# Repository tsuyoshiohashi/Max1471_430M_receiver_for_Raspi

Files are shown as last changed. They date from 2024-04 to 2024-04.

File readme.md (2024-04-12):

# MAX1471＋AD5700 430MHz AFSK receiver for Raspi

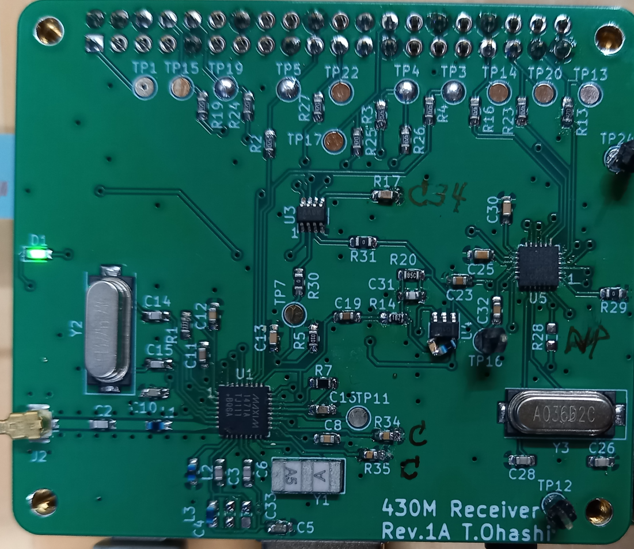
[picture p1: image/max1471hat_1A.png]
Max1471_hat max1471_hat


Receive 1200bps AFSK modulated waves in the 430Mhz band with RaspberryPi and an expansion board (MAX1471 + AD5700 430M radio hat, home made, see hat directory).
(In the photo, the LC series trap is directly attached to the U4 pin, but it has been modified in the circuit diagram.)

・The receiving frequency is fixed at the frequency determined by the XTAL frequency.

-Confirmed reception of a 1200bps AFSK signal in Asynchronous format (UART) sent by Gnuradio+Pluto. 

Please refer to the gnuradio directory for the transmitting program.

# Environment where operation has been confirmed
Raspi3B+　Raspberry Pi OS(bookworm)

You need to install pigpio.

# HAT configuration and operation
I use Analog Devices' MAX1471 for reception and AD5700 for AFSK demodulation.

MAX1471 operates in Continuous Receive Mode.

## receiving data
The received data RXD is connected to GPIO15 (pin10) of Raspi, and if the received data is in UART format, it can be treated as /dev/ttyAMA0 by setting UART on Raspi, and it can be displayed on minicom.
(Device name may vary depending on Raspino model)

`Example) $ cat /dev/ttyAMA0`

`Example) $ minicom -b 1200 -D /dev/ttyAMA0`

Since there is no squelch, the data becomes meaningless when there is no signal.

You can determine whether there is a received signal by looking at the CD signal of the AD5700 or by the size of the RSSI signal.

Please refer to rxafsk.py.

## receiving frequency
The receiving frequency is determined by the Xtal frequency using the following formula.
$$ frx = (fxtal * 32) + 10.7 (MHz) $$

13.2256MHz becomes 433.920MHz.

Although the data sheet says, the sensitivity is higher at frequencies slightly lower than this.
The prototype board had better sensitivity at frequencies several tens of KHz lower.

If you want to change the receiving frequency, you must also change the value of register 3 to fxtal/100kHz. (FREQ_XTAL in rxafskconst.py Please check the data sheet for details.)

# Software

The SPI of MAX1471 is controlled from the Raspi, but it is controlled by itself via GPIO, so there is no need to configure the SPI of the Raspi.
If SPI0 is enabled, please disable it. (Access as GPIO)

## rxafsk.py

If you run it from the command line as $ python rxafsk.py, it will perform the receiving operation.

Place regs.py, rxafskconst.py, and spi.py in the same directory.

When you run it, a prompt like "H>" will appear, allowing you to enter commands.

The prompt color is green when the synthesizer is locked, and red when it is not locked. (LOCKDET bit in Status Register)

When the LNA is High-gain, it is "H>", and when it is Low-gain, it is "L>".

A history function allows you to display and re-enter command history.

### Command
The following commands can be entered when the prompt is displayed.
### reset
Reset and initialize the MAX1471 and AD5700.

### rssi/r
Measures the received RSSI voltage and displays it in V units.

### cal/fskcal
Calibrate the FSK demodulator of MAX1471.

For some reason, sometimes (especially when receiving a weak signal?) when I perform calibration, the reception sensitivity and FSK signal output size change, and the signal that I was able to receive before can no longer be received (sensitivity worsens). The cause is unknown...
If you calibrate again, it will usually return to normal.

The data sheet says it is necessary if the voltage or temperature changes, but it may be better not to do this when reception is normal.

### read/rd n
Reads the contents of register number n (0-3,9) of MAX1471 and displays it in binary.

example:

H>read 0

Reg 0 = 11110110

### read/rd cd
Read the CD signal of AD5700.

### write/wr n data
Write data to register n of MAX1471. Enter data in hexadecimal.

example:

H>wr 0 f6

H>rd 0

Reg 0 = 11110110

===

Have A Fun!

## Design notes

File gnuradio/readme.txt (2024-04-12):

Pluto_432_tx_afsk.py is tested with Gnuradio 3.10.7.0.
External Attenetor 40dB is inserted in my test.

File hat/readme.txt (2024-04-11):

Edited with Kicad ver.7
It may not have been replicated properly.

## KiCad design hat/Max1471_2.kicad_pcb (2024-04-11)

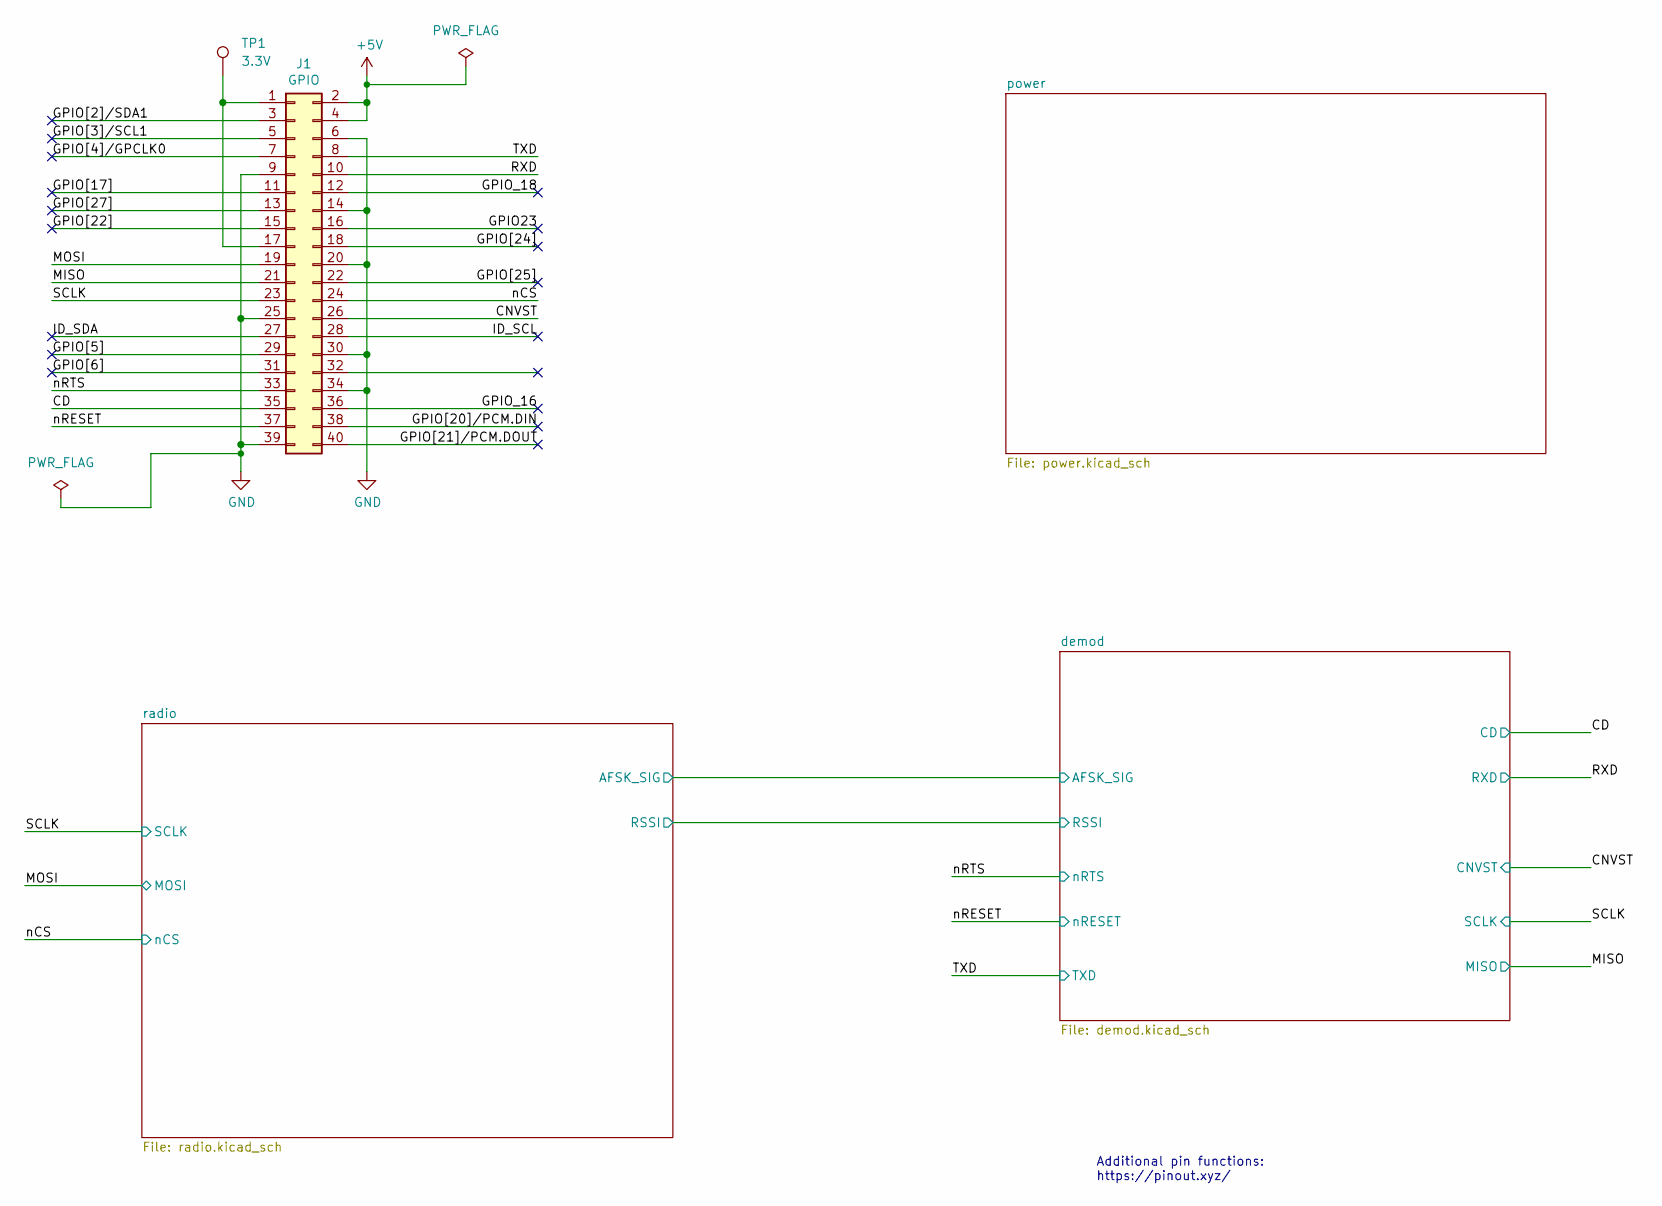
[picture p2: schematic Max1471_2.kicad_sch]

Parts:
J1: GPIO; PinSocket_2x20_P2.54mm_Vertical
TP1: 3.3V; TestPoint_Pad_D2.0mm

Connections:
+5V: J1.2, J1.4; also elsewhere on the board
/CD: J1.35; also elsewhere on the board
/CNVST: J1.26; also elsewhere on the board
/GPIO23: J1.16
/GPIO[2]/SDA1: J1.3
/GPIO[3]/SCL1: J1.5
/GPIO[4]/GPCLK0: J1.7
/GPIO[5]: J1.29
/GPIO[6]: J1.31
/GPIO[17]: J1.11
/GPIO[20]/PCM.DIN: J1.38
/GPIO[21]/PCM.DOUT: J1.40
/GPIO[22]: J1.15
/GPIO[24]: J1.18
/GPIO[25]: J1.22
/GPIO[27]: J1.13
/GPIO_16: J1.36
/GPIO_18: J1.12
/ID_SCL: J1.28
/ID_SDA: J1.27
/MISO: J1.21; also elsewhere on the board
/MOSI: J1.19; also elsewhere on the board
/RXD: J1.10; also elsewhere on the board
/SCLK: J1.23; also elsewhere on the board
/TXD: J1.8; also elsewhere on the board
/nCS: J1.24; also elsewhere on the board
/nRESET: J1.37; also elsewhere on the board
/nRTS: J1.33; also elsewhere on the board
GND: J1.6, J1.9, J1.14, J1.20, J1.25, J1.30, J1.34, J1.39; also elsewhere on the board
unnamed: J1.1, J1.17, TP1.1

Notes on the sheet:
Additional pin functions: https://pinout.xyz/

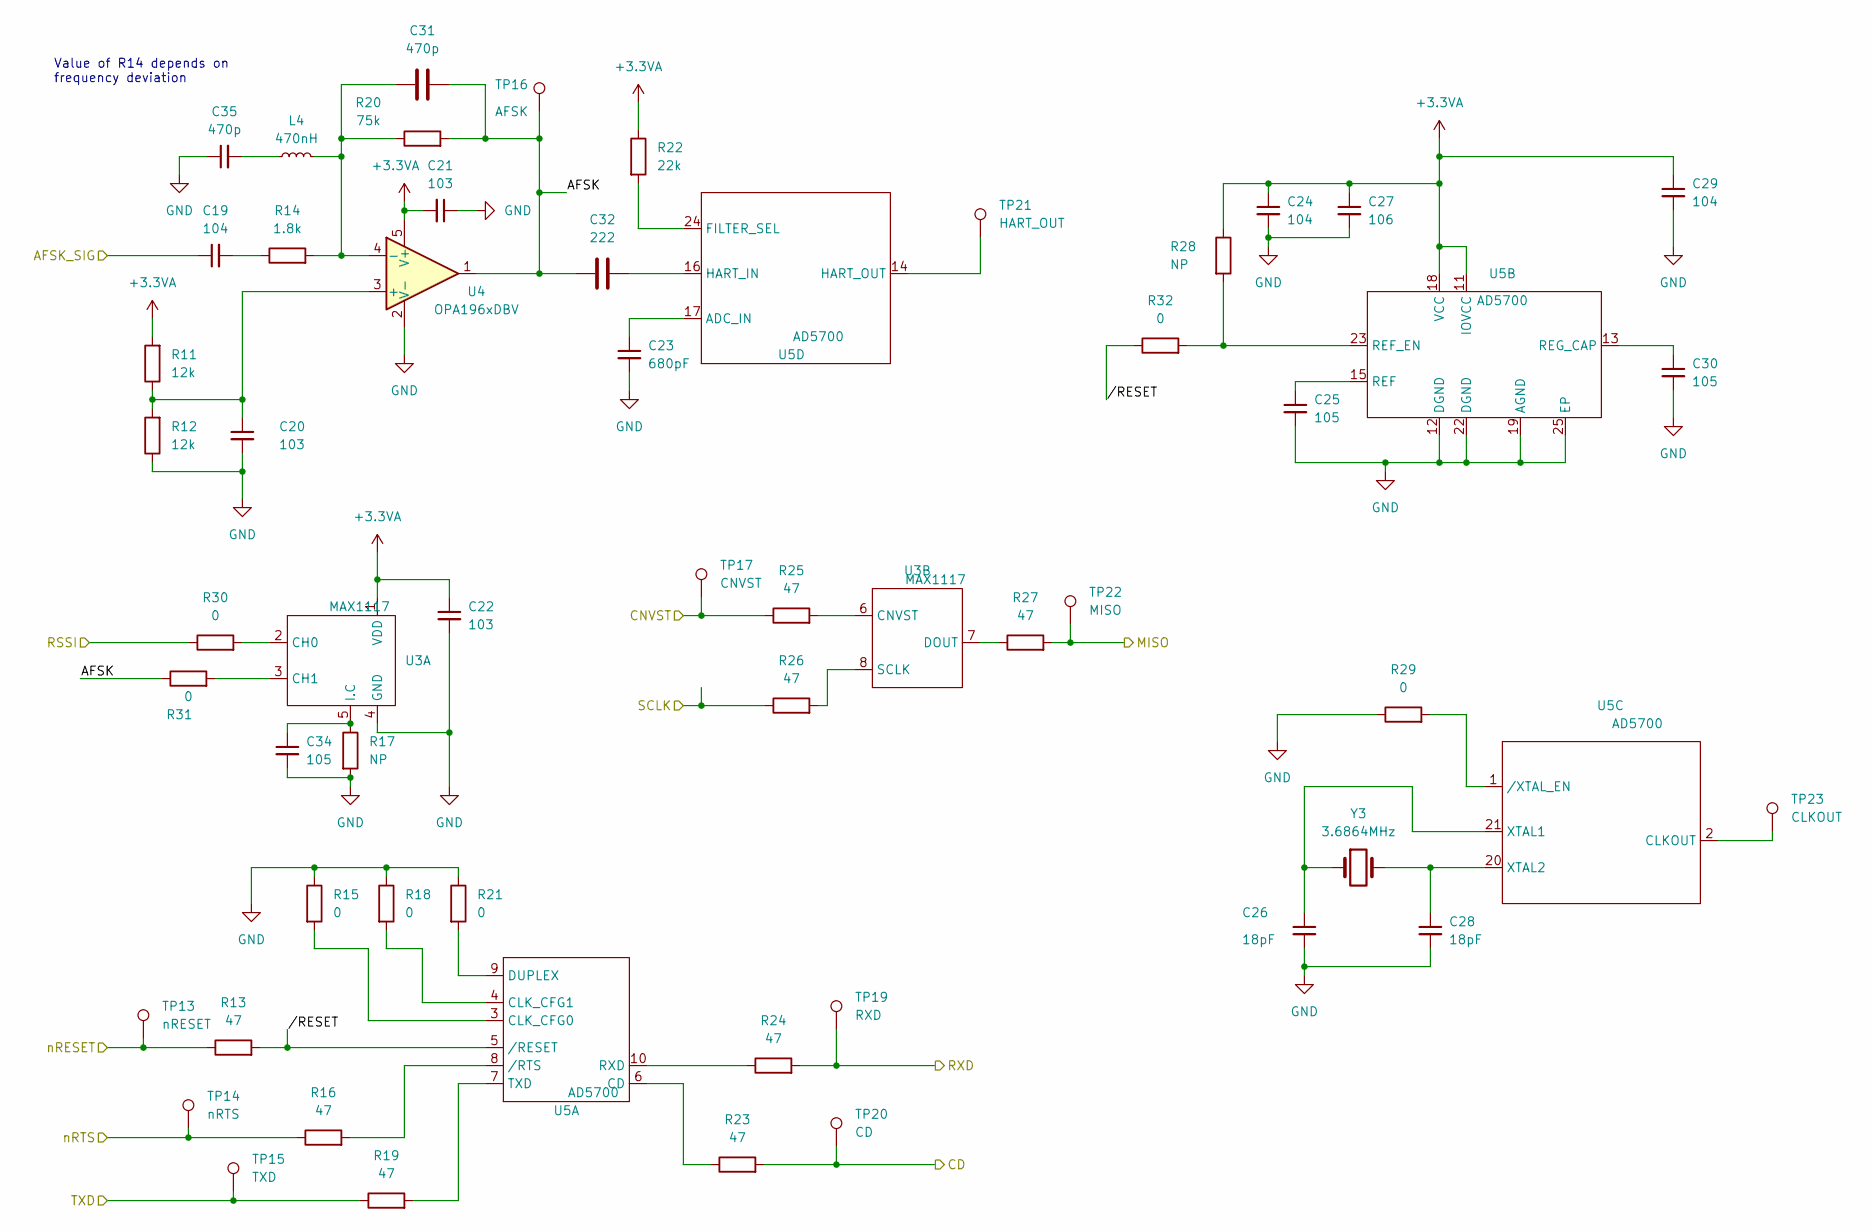
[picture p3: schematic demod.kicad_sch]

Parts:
C19, C24, C29: 104; C_0603_1608Metric_Pad1.08x0.95mm_HandSolder
C20, C21, C22: 103; C_0603_1608Metric_Pad1.08x0.95mm_HandSolder
C23: 680pF; C_0603_1608Metric_Pad1.08x0.95mm_HandSolder
C25, C30, C34: 105; C_0603_1608Metric_Pad1.08x0.95mm_HandSolder
C26, C28: 18pF; C_0603_1608Metric_Pad1.08x0.95mm_HandSolder
C27: 106; C_0603_1608Metric_Pad1.08x0.95mm_HandSolder
C31, C35: 470p; C_0603_1608Metric_Pad1.08x0.95mm_HandSolder
C32: 222; C_0603_1608Metric_Pad1.08x0.95mm_HandSolder
L4: 470nH; L_0603_1608Metric_Pad1.05x0.95mm_HandSolder
R11, R12: 12k; R_0603_1608Metric_Pad0.98x0.95mm_HandSolder
R13, R16, R19, R23, R24, R25, R26, R27: 47; R_0603_1608Metric_Pad0.98x0.95mm_HandSolder
R14: 1.8k; R_0603_1608Metric_Pad0.98x0.95mm_HandSolder
R15, R18, R21, R29, R30, R31, R32: 0; R_0603_1608Metric_Pad0.98x0.95mm_HandSolder
R17, R28: NP; R_0603_1608Metric_Pad0.98x0.95mm_HandSolder
R20: 75k; R_0603_1608Metric_Pad0.98x0.95mm_HandSolder
R22: 22k; R_0603_1608Metric_Pad0.98x0.95mm_HandSolder
TP13: nRESET; TestPoint_Pad_D2.0mm
TP14: nRTS; TestPoint_Pad_D2.0mm
TP15: TXD; TestPoint_Pad_D2.0mm
TP16: AFSK; TestPoint_Pad_D2.0mm
TP17: CNVST; TestPoint_Pad_D2.0mm
TP19: RXD; TestPoint_Pad_D2.0mm
TP20: CD; TestPoint_Pad_D2.0mm
TP21: HART_OUT; TestPoint_Pad_D2.0mm
TP22: MISO; TestPoint_Pad_D2.0mm
TP23: CLKOUT; TestPoint_Pad_D2.0mm
U3: MAX1117; SOT-23-8
U4: OPA196xDBV; SOT-23-5
U5: AD5700; QFN-24-1EP_4x4mm_P0.5mm_EP2.15x2.15mm
Y3: 3.6864MHz; Crystal_SMD_HC49-SD

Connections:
+3.3VA: C21.2, C22.1, C24.1, C27.1, C29.1, R11.2, R22.1, R28.1, U3.1 (VDD), U4.5 (V+), U5.11 (IOVCC), U5.18 (VCC); also elsewhere on the board
/CD: R23.2, TP20.1; also elsewhere on the board
/CNVST: R25.1, TP17.1; also elsewhere on the board
/MISO: R27.2, TP22.1; also elsewhere on the board
/RXD: R24.2, TP19.1; also elsewhere on the board
/SCLK: R26.1; also elsewhere on the board
/TXD: R19.1, TP15.1; also elsewhere on the board
/demod/AFSK: C31.2, C32.1, R20.2, R31.1, TP16.1, U4.1
/demod/AFSK_SIG: C19.1; also elsewhere on the board
/demod/RSSI: R30.1; also elsewhere on the board
/demod//RESET: R13.2, R32.1, U5.5 (/RESET)
/nRESET: R13.1, TP13.1; also elsewhere on the board
/nRTS: R16.1, TP14.1; also elsewhere on the board
GND: C20.2, C21.1, C22.2, C23.2, C24.2, C25.2, C26.2, C27.2, C28.2, C29.2, C30.2, C34.2, C35.1, R12.1, R15.1, R17.2, R18.1, R21.1, R29.1, U3.4 (GND), U4.2 (V-), U5.12 (DGND), U5.19 (AGND), U5.22 (DGND), U5.25 (EP); also elsewhere on the board
unnamed: C19.2, R14.1
unnamed: C35.2, L4.1
unnamed: R30.2, U3.2 (CH0)
unnamed: R31.2, U3.3 (CH1)
unnamed: C34.1, R17.1, U3.5 (I.C)
unnamed: R25.2, U3.6 (CNVST)
unnamed: R27.1, U3.7 (DOUT)
unnamed: R26.2, U3.8 (SCLK)
unnamed: C20.1, R11.1, R12.2, U4.3 (+)
unnamed: C31.1, L4.2, R14.2, R20.1, U4.4 (-)
unnamed: R23.1, U5.6 (CD)
unnamed: R15.2, U5.3 (CLK_CFG0)
unnamed: R18.2, U5.4 (CLK_CFG1)
unnamed: R21.2, U5.9 (DUPLEX)
unnamed: R24.1, U5.10 (RXD)
unnamed: R19.2, U5.7 (TXD)
unnamed: R16.2, U5.8 (/RTS)
unnamed: C25.1, U5.15 (REF)
unnamed: R28.2, R32.2, U5.23 (REF_EN)
unnamed: C30.1, U5.13 (REG_CAP)
unnamed: TP23.1, U5.2 (CLKOUT)
unnamed: C26.1, U5.21 (XTAL1), Y3.1
unnamed: C28.1, U5.20 (XTAL2), Y3.2
unnamed: R29.2, U5.1 (/XTAL_EN)
unnamed: C23.1, U5.17 (ADC_IN)
unnamed: R22.2, U5.24 (FILTER_SEL)
unnamed: C32.2, U5.16 (HART_IN)
unnamed: TP21.1, U5.14 (HART_OUT)

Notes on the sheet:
Value of R14 depends on frequency deviation

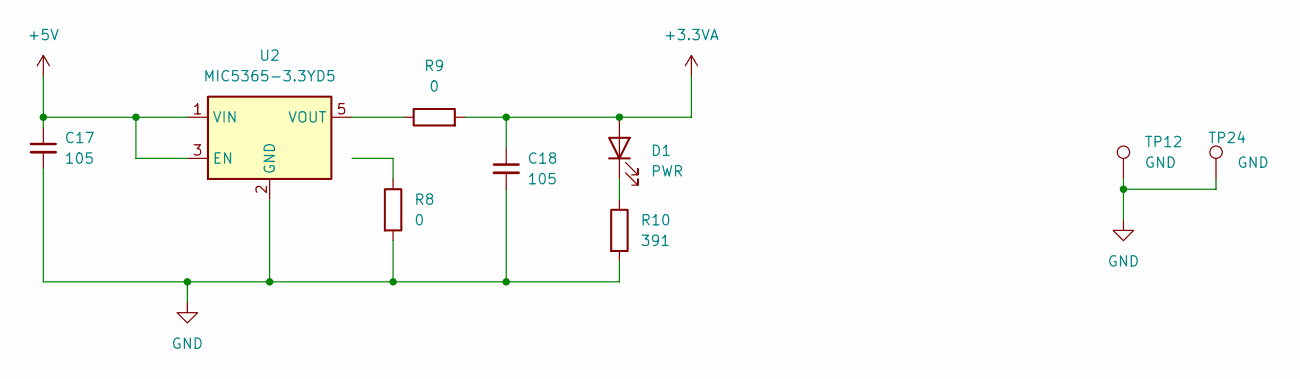
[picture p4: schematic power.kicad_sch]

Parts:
C17, C18: 105; C_0603_1608Metric_Pad1.08x0.95mm_HandSolder
D1: PWR; LED_0603_1608Metric_Pad1.05x0.95mm_HandSolder
R8, R9: 0; R_0603_1608Metric_Pad0.98x0.95mm_HandSolder
R10: 391; R_0603_1608Metric_Pad0.98x0.95mm_HandSolder
TP12, TP24: GND; TestPoint_Pad_D2.0mm
U2: MIC5365-3.3YD5; SOT-23-5

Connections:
+3.3VA: C18.1, D1.2 (A), R9.2; also elsewhere on the board
+5V: C17.1, U2.1 (VIN), U2.3 (EN); also elsewhere on the board
GND: C17.2, C18.2, R8.2, R10.2, TP12.1, TP24.1, U2.2 (GND); also elsewhere on the board
unnamed: D1.1 (K), R10.1
unnamed: R8.1, U2.4 (NC)
unnamed: R9.1, U2.5 (VOUT)

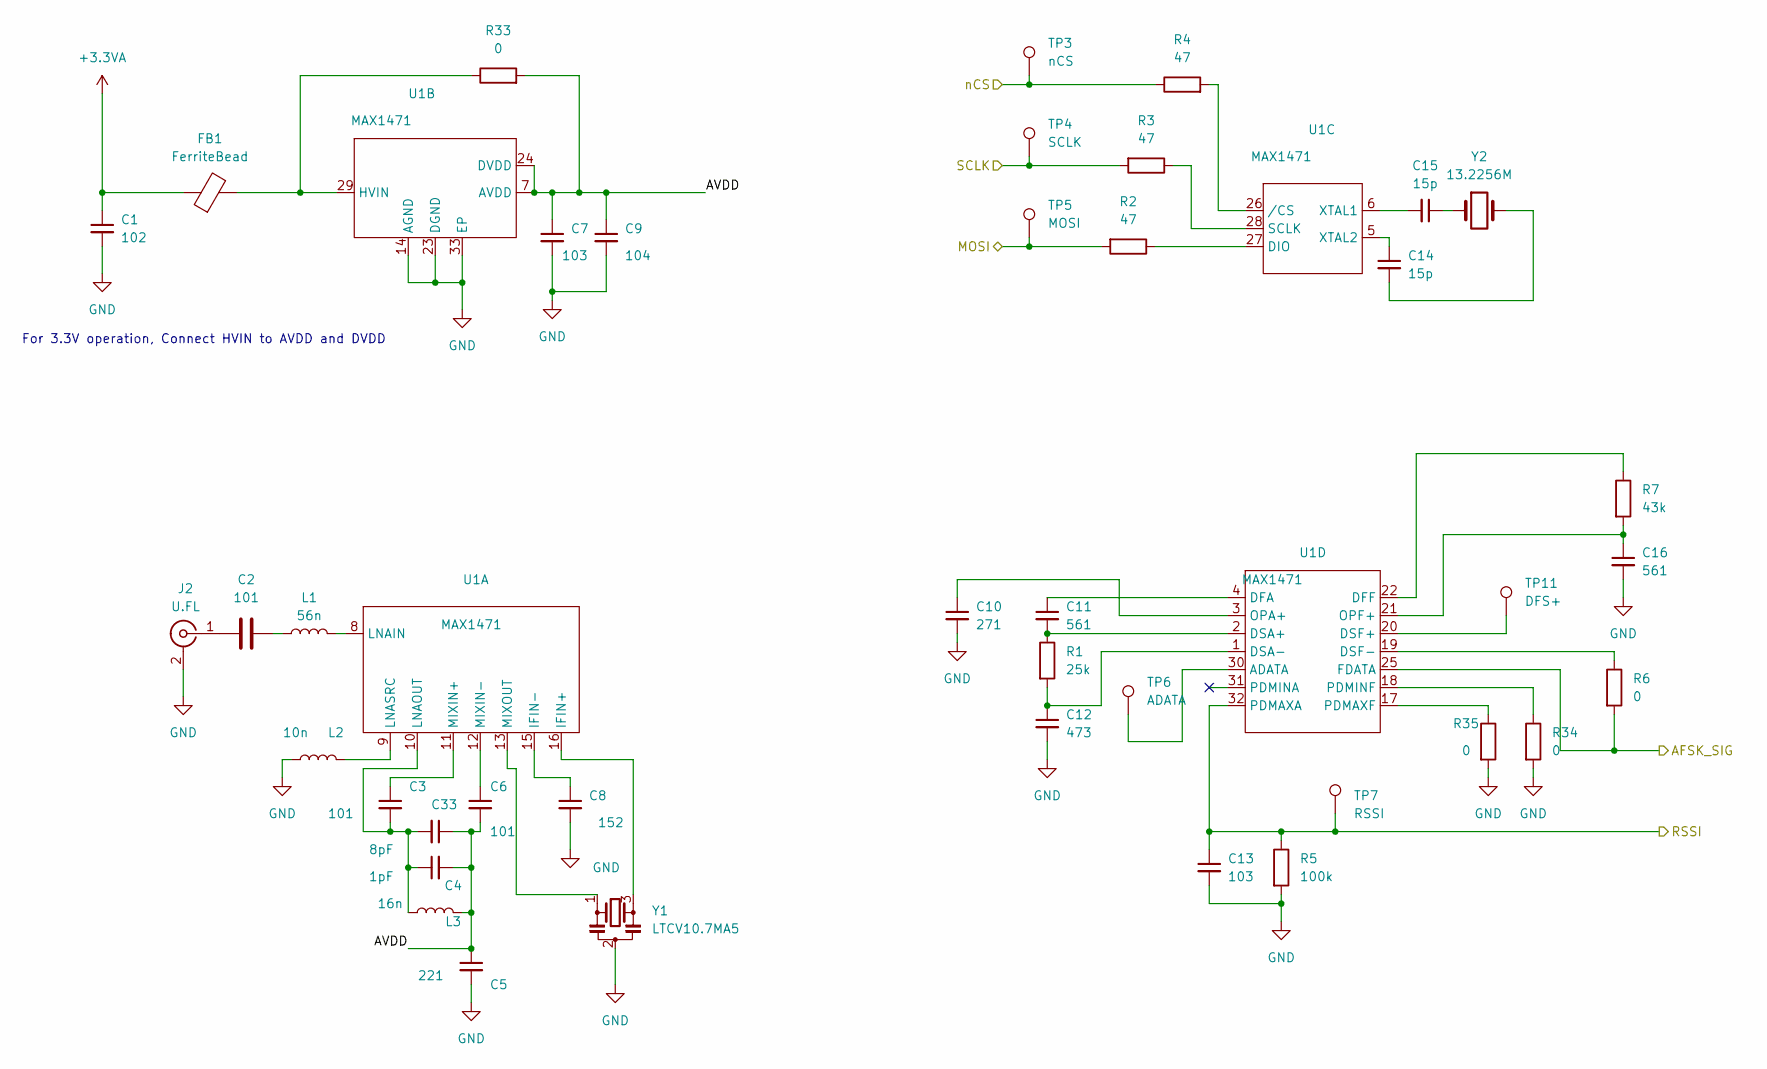
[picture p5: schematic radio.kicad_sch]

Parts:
C1: 102; C_0603_1608Metric_Pad1.08x0.95mm_HandSolder
C2, C3, C6: 101; C_0603_1608Metric_Pad1.08x0.95mm_HandSolder
C4: 1pF; C_0603_1608Metric_Pad1.08x0.95mm_HandSolder
C5: 221; C_0603_1608Metric_Pad1.08x0.95mm_HandSolder
C7, C13: 103; C_0603_1608Metric_Pad1.08x0.95mm_HandSolder
C8: 152; C_0603_1608Metric_Pad1.08x0.95mm_HandSolder
C9: 104; C_0603_1608Metric_Pad1.08x0.95mm_HandSolder
C10: 271; C_0603_1608Metric_Pad1.08x0.95mm_HandSolder
C11, C16: 561; C_0603_1608Metric_Pad1.08x0.95mm_HandSolder
C12: 473; C_0603_1608Metric_Pad1.08x0.95mm_HandSolder
C14, C15: 15p; C_0603_1608Metric_Pad1.08x0.95mm_HandSolder
C33: 8pF; C_0603_1608Metric_Pad1.08x0.95mm_HandSolder
FB1: FerriteBead; L_0603_1608Metric_Pad1.05x0.95mm_HandSolder
J2: U.FL; U.FL_Hirose_U.FL-R-SMT-1_Vertical
L1: 56n; L_0603_1608Metric_Pad1.05x0.95mm_HandSolder
L2: 10n; L_0603_1608Metric_Pad1.05x0.95mm_HandSolder
L3: 16n; L_0603_1608Metric_Pad1.05x0.95mm_HandSolder
R1: 25k; R_0603_1608Metric_Pad0.98x0.95mm_HandSolder
R2, R3, R4: 47; R_0603_1608Metric_Pad0.98x0.95mm_HandSolder
R5: 100k; R_0603_1608Metric_Pad0.98x0.95mm_HandSolder
R6, R33, R34, R35: 0; R_0603_1608Metric_Pad0.98x0.95mm_HandSolder
R7: 43k; R_0603_1608Metric_Pad0.98x0.95mm_HandSolder
TP3: nCS; TestPoint_Pad_D2.0mm
TP4: SCLK; TestPoint_Pad_D2.0mm
TP5: MOSI; TestPoint_Pad_D2.0mm
TP6: ADATA; TestPoint_Pad_D2.0mm
TP7: RSSI; TestPoint_Pad_D2.0mm
TP11: DFS+; TestPoint_Pad_D2.0mm
U1: MAX1471; QFN-32-1EP_5x5mm_P0.5mm_EP3.1x3.1mm
Y1: LTCV10.7MA5; LTCV10.7M
Y2: 13.2256M; Crystal_SMD_HC49-SD

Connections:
+3.3VA: C1.1, FB1.1; also elsewhere on the board
/MOSI: R2.2, TP5.1; also elsewhere on the board
/SCLK: R3.2, TP4.1; also elsewhere on the board
/demod/AFSK_SIG: R6.2, U1.25 (FDATA); also elsewhere on the board
/demod/RSSI: C13.1, R5.1, TP7.1, U1.32 (PDMAXA); also elsewhere on the board
/nCS: R4.1, TP3.1; also elsewhere on the board
/radio/AVDD: C4.2, C5.1, C6.2, C7.1, C9.1, C33.1, L3.2, R33.2, U1.7 (AVDD), U1.24 (DVDD)
GND: C1.2, C5.2, C7.2, C8.2, C9.2, C10.2, C12.2, C13.2, C16.2, J2.2 (Ext), L2.2, R5.2, R34.2, R35.2, U1.14 (AGND), U1.23 (DGND), U1.33 (EP), Y1.2; also elsewhere on the board
unnamed: C2.2, L1.1
unnamed: C14.2, Y2.2
unnamed: C15.1, Y2.1
unnamed: C2.1, J2.1 (In)
unnamed: U1.16 (IFIN+), Y1.3
unnamed: C8.1, U1.15 (IFIN-)
unnamed: L1.2, U1.8 (LNAIN)
unnamed: C3.2, C4.1, C33.2, L3.1, U1.10 (LNAOUT)
unnamed: L2.1, U1.9 (LNASRC)
unnamed: C3.1, U1.11 (MIXIN+)
unnamed: C6.1, U1.12 (MIXIN-)
unnamed: U1.13 (MIXOUT), Y1.1
unnamed: FB1.2, R33.1, U1.29 (HVIN)
unnamed: R2.1, U1.27 (DIO)
unnamed: R3.1, U1.28 (SCLK)
unnamed: C15.2, U1.6 (XTAL1)
unnamed: C14.1, U1.5 (XTAL2)
unnamed: R4.2, U1.26 (/CS)
unnamed: TP6.1, U1.30 (ADATA)
unnamed: C11.1, U1.4 (DFA)
unnamed: R7.1, U1.22 (DFF)
unnamed: C11.2, R1.1, U1.2 (DSA+)
unnamed: C12.1, R1.2, U1.1 (DSA-)
unnamed: TP11.1, U1.20 (DSF+)
unnamed: R6.1, U1.19 (DSF-)
unnamed: C10.1, U1.3 (OPA+)
unnamed: C16.1, R7.2, U1.21 (OPF+)
unnamed: R35.1, U1.17 (PDMAXF)
unnamed: R34.1, U1.18 (PDMINF)

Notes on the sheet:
For 3.3V operation, Connect HVIN to AVDD and DVDD

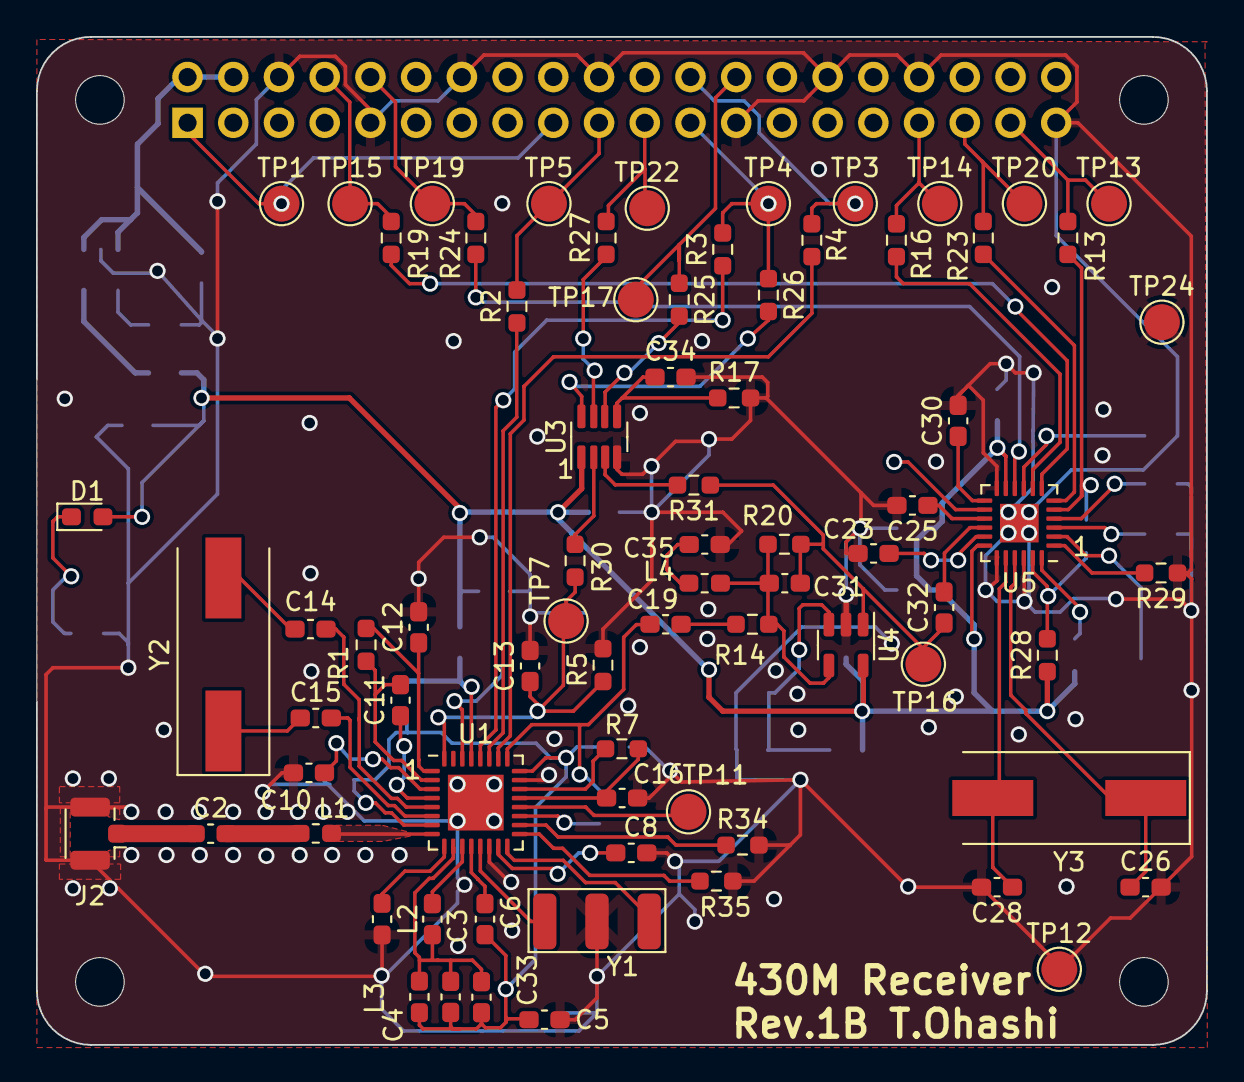
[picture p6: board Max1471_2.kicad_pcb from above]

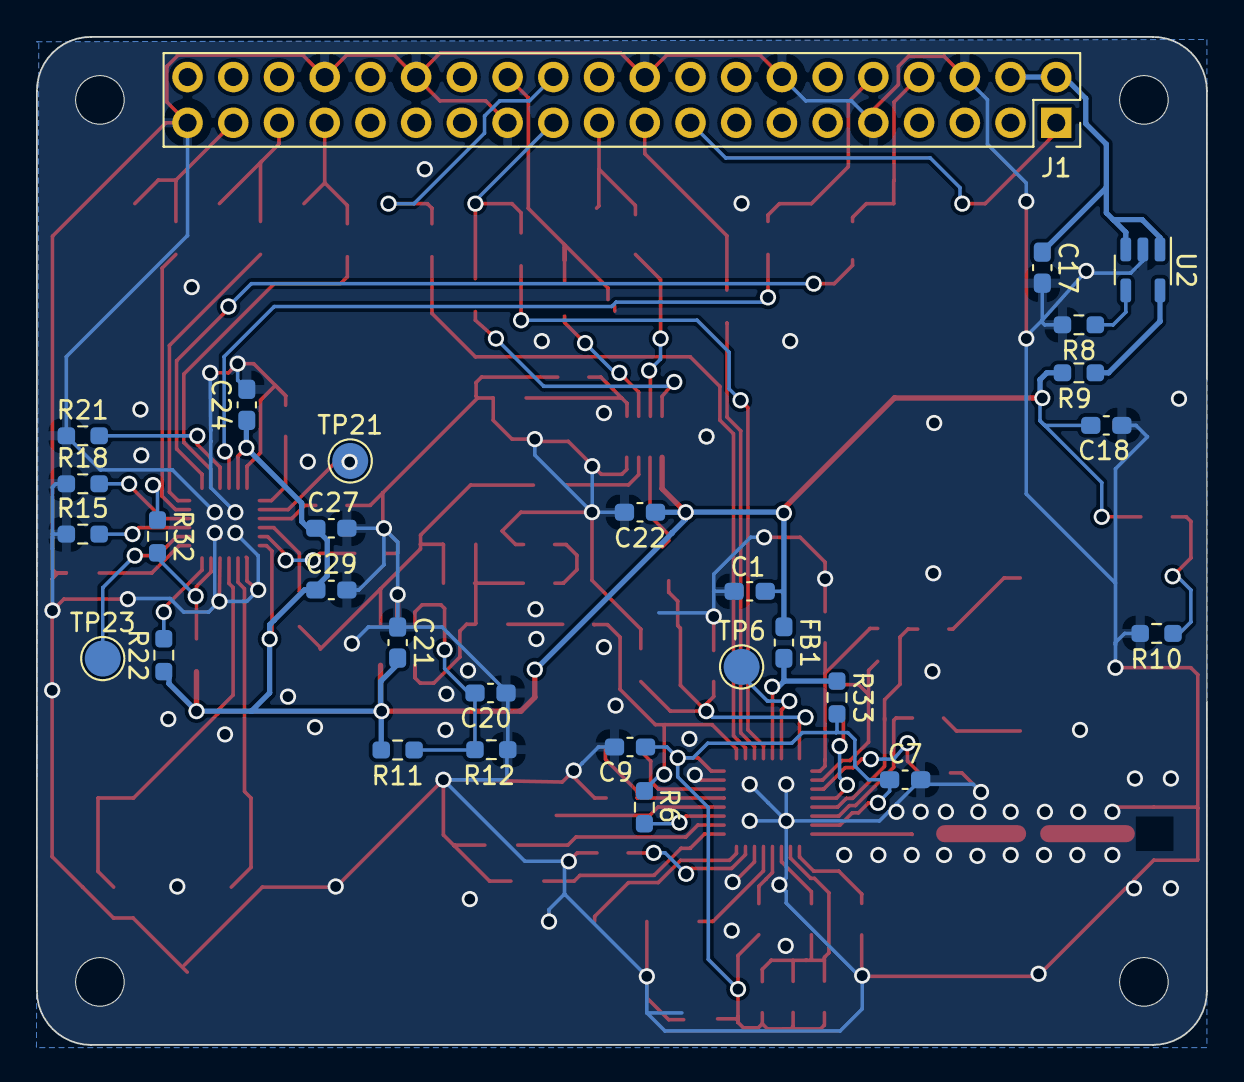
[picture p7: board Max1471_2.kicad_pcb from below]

Board: 2 copper layers, 65.0 x 56.0 mm, 109 parts (29 on the bottom side), 79 nets.

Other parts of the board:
MH1, MH2, MH3, MH4: MountingHole_2.7mm_M2.5

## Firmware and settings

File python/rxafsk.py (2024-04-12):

#!/usr/bin/env python3
#
# rxafsk.py
# driver fot raspi max1471+ad5700+max1117 430M receiver hat(my own work, see hat directory)
# 
# This implementation is for personal experiments.
# Copyright (c) 2024 Tsuyoshi Ohashi
# Released under the MIT license
# https://opensource.org/licenses/mit-license.php
#
import pigpio
import time
import readline
import os

from rxafskconst import *
from spi import Spi
from regs import *

__version__ = "2024.3.21"

# debug flag
debug = False   #True

class RxAfsk:
        
    def __init__(self):
        self.reg0 = Reg0()
        self.reg1 = Reg1()
        self.reg2 = Reg2()
        self.reg3 = Reg3()
        self.spi = Spi()          
    #
    def reset_master(self):
        cmd = CMD_RESET
        adrs = 0x0
        data = 0x0
        to_send = cmd<<12 | adrs<<8 | data
        self.spi._wr( to_send)
    
    # get register_9 ( Status Register)
    def read_reg9(self):
        cmd = CMD_READ
        adrs = 0x9
        data = 0x0
        to_send = cmd<<12 | adrs<<8 | data
        self.spi._wr(to_send)
        rd_data = self.spi._rd()
        lockdet = (rd_data>>7) & 0b1
        agcst = (rd_data>>6) & 0b1
        clkalive = (rd_data>>5) & 0b1
        pol_cal_done = (rd_data>>1) & 0b1
        fsk_cal_done = rd_data & 0b1

        return lockdet, agcst, clkalive, pol_cal_done, fsk_cal_done
    
    def get_ld(self):
        lockdet,_,_,_,_= self.read_reg9()
        return lockdet
        
    def setup(self):
        if(debug):
            print("setup")
            
        # Send Master Reset command
        self.reset_master()        
        
        # write registers max1471
        self.reg0.write()
        self.reg3.write()
        self.reg1.write()    
        self.reg2.write() 
        # setup ad5700
        self.spi._reset57()
        self.spi._rts(1)
        
    # Read voltage(ch0=RSSI, ch1=AFSK) 
    # return : voltage
    def get_adc_reading(self, ch=0):
        if(debug):
            print("get_adc_reading")
        # ch1 only
        if(ch==1):
            self.spi._cnvst()
        # ch0 and ch1
        self.spi._cnvst()
        data = 0
        self.spi._clk(0)
        for _ in range(8):
            self.spi._clk(1)
            data = data<<1
            bit = self.spi._rd_miso()
            data += bit
            self.spi._clk(0)
        
        return data
   
    #
    def __del__(self):
        del self.reg0
        del self.reg1
        del self.reg2
        del self.reg3
        del self.spi

# help message 
def show_help():
    print("commands: ")
    print("reset: reset and initialize MAX1471 and AD5700")
    print("rssi/r: get and show rssi")
    print("cal/fskcal: Calibrate FSK demod")
    print("read/rd n : Read register n(0-3)")
    print("read/rd cd : Read CD signal")
    print("write/wr n m : Read register n(0-3) data m(hex)")
    print("help : Show this help")

###
if __name__ == '__main__':
    print("rxafsk.py  ver.", __version__ )
    
    rxafsk = RxAfsk()
    # setup, reset and initialize 
    rxafsk.setup()
    
    # read reg9
    lockdet, agcst, clkalive, pol_cal_done, fsk_cal_done = rxafsk.read_reg9()
    print("lockdet:", lockdet)
    print("agcst:", agcst)
    print("clkalive:", clkalive)
    print("pol_cal_done:", pol_cal_done)
    print("fsk_cal_done:", fsk_cal_done)
    
    ###
    HISTORY_FILE = os.path.expanduser('~/.rxafsk_history')
    if os.path.exists(HISTORY_FILE):
        readline.read_history_file(HISTORY_FILE)
    ### Let's go!
    while(1):
        lockdet, agcst, clkalive, pol_cal_done, fsk_cal_done = rxafsk.read_reg9()
        p_start = "\033[32m" if (lockdet) else "\033[31m"   # Lock:Green/ Unlock:Red 
        p_end = "\033[0m"
        p1 = ">"
        p2 = "H" if(agcst==1) else ("L")
        #p2,p3,p4,p5 = str(agcst), str(clkalive), str(pol_cal_done), str(fsk_cal_done)
        cmd_line = input( p_start + p2 + p1 + p_end)
        readline.write_history_file(HISTORY_FILE)
        cmd = cmd_line.split()
        if( len(cmd)==0):
            pass
        elif(cmd[0]=="reset"):
            rxafsk.setup()
            
        elif(cmd[0]=="rssi" or cmd[0]=="r"):
            rssi_lvl = rxafsk.get_adc_reading(ch=0)
            #print("rssi: ", rssi_lvl)
            rssi_vol = 2.048 *rssi_lvl / 256
            print(f"rssi : { rssi_vol:.3f}　V")
            #_,agcst,_,_,_ = rxafsk.read_reg9()
            #print("agcst:", agcst)
            
        elif(cmd[0]=="cal" or cmd[0]=="fskcal"):
            rxafsk.reg2.fsk_cal_en = 1
            rxafsk.reg2.write()
            _, _, _, _, fsk_cal_done = rxafsk.read_reg9()
            print("fsk_cal_done:", fsk_cal_done)
            
        # Read Register 0-3,9 and CD   
        elif(cmd[0]=="read" or cmd[0]=="rd"):
            try:
                if(cmd[1]=="0"):
                    rd_data = rxafsk.reg0.read()
                    print("Reg",cmd[1],"= {:08b}".format(rd_data))
                elif(cmd[1]=="1"):
                    rd_data = rxafsk.reg1.read()
                    print("Reg",cmd[1],"= {:08b}".format(rd_data))
                elif(cmd[1]=="2"):
                    rd_data = rxafsk.reg2.read()
                    print("Reg",cmd[1],"= {:08b}".format(rd_data))
                elif(cmd[1]=="3"):
                    rd_data = rxafsk.reg3.read()
                    print("Reg",cmd[1],"= {:08b}".format(rd_data))
                elif(cmd[1]=="9"):
                    rd_data = rxafsk.read_reg9()
                    print("Reg",cmd[1],"= ", rd_data)
                elif(cmd[1]=="cd"):
                    bit_cd = rxafsk.spi._det_cd()
                    print("CD: ", bit_cd)
                else:
                    print("Specify correct register no")
            except:
                print("Specify register no")    
                
        # Write Register 0-3   
        elif(cmd[0]=="write" or cmd[0]=="wr"):
            try:
                wr_data = int(cmd[2],16)
                if(cmd[1]=="0"):
                    rxafsk.reg0.power_config = wr_data
                    rxafsk.reg0.write()
                elif(cmd[1]=="1"):
                    rxafsk.reg1.config = wr_data
                    print(hex(wr_data))
                    rxafsk.reg1.write()
                elif(cmd[1]=="2"):
                    rxafsk.reg2.control = wr_data
                    rxafsk.reg2.write()
                elif(cmd[1]=="3"):
                    rxafsk.reg3.xtal = wr_data
                    rxafsk.reg3.write()
            except:
                print("Invalid command")   
                
        ## quit/exit
        elif(cmd[0]=="quit" or cmd[0]=="exit" or cmd[0]=="q" or cmd[0]=="e"):
            print("Bye!")
            exit()
        elif(cmd[0]=="help" or cmd[0]=="h"):
             show_help()        
        # unknown command
        else:
            print("Sorry,not in command list.")
            show_help()    
    # 
    del rxafsk
### end of rxafsk.py

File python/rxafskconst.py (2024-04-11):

#
# rxafskconst.py
# parameters for regs.py, spi.py and rxafsk.py 

# This implementation is for personal experiments.
# Copyright (c) 2024 Tsuyoshi Ohashi
# Released under the MIT license
# https://opensource.org/licenses/mit-license.php

# GPIO pin config
# device_name - BCM# - raspi_IO_pin#
# SoftSPI (NOT BCM system SPI)
GPIO_nCS = 8   # GPIO8 = pin24
GPIO_MOSI = 10    # GPIO10 = pin19  # max1471 Bi-directional

GPIO_MISO = 9    # GPIO9 = pin21    # max1117(ADC)
GPIO_SCLK = 11   # GPIO11 = pin23

GPIO_nRTS = 13  # GPIO13 = pin33
GPIO_nRESET = 26 # GPIO26 = pin37
GPIO_CD = 19 # GPIO19 = pin35
TXD = 8 #  
RXD = 10 # 

#max1117
# down edge starts convert
# 1 edge for CH0, 2 edgs for CH1
GPIO_CNVST = 7 # GPIO7 = pin26
 
#GPIO1 = 6   # GPIO6 = pin31
#GPIO2 = 27  # GPIO27 = pin13
#GPIO3 = 17  # GPIO17 = pin11
#GPIOSDN = 4 # GPIO4 = pin7
#GPIOnIRQ = 5   # GPIO05 = pin29

# Config GPIO
#GPIO_TX_DATA = GPIO0 
#GPIO_CTS = GPIO1
#GPIO_SHDN = GPIOSDN

# Commands for max1471
CMD_NOP = 0x0
CMD_WRITE = 0x1
CMD_READ = 0x2
CMD_RESET = 0x3

# Registers in max1471
REG_PWR_CFG = 0x0
REG_CONFIG = 0x1
REG_CONTROL = 0x2
REG_OSC_FREQ = 0x3
REG_STATUS = 0x9
REG_AGC_DWELL = 0xA

# XTAL
FREQ_XTAL = 0x84  # 13.2256MHz/100kHz=132=0x84 

###
